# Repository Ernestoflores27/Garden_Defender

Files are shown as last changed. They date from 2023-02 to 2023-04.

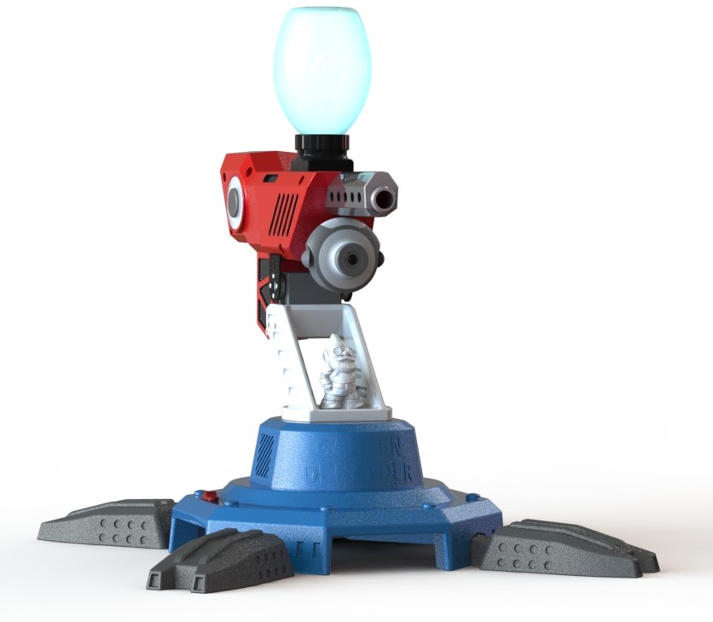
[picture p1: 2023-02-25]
Mechanical Design/Renders/V2/2.JPG

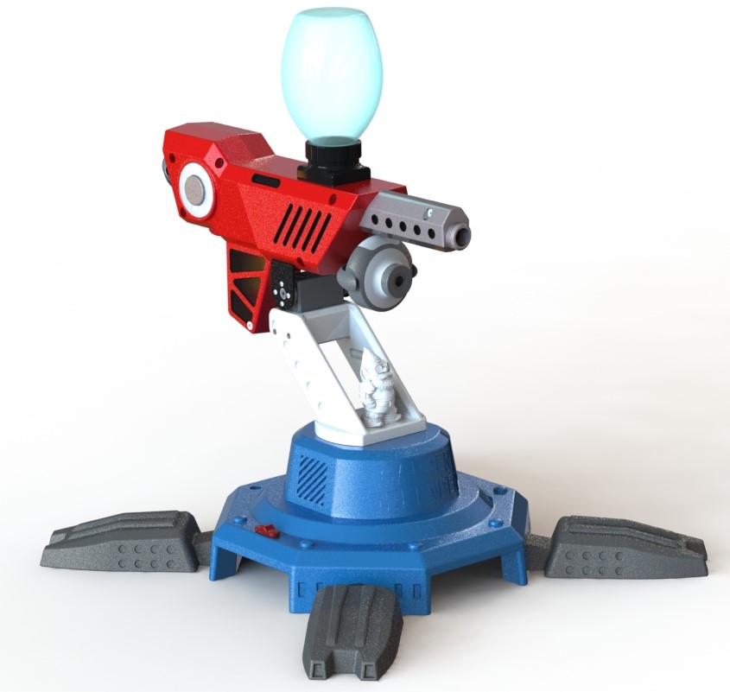
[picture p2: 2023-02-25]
Mechanical Design/Renders/V2/4.JPG

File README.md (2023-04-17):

# Garden_Defender   

Garden Defender Logo

# Description
WhatsApp Image 2023-04-06 at 18 43 52

Protect your garden from unwanted animals with the garden defender. The garden defender is a robotic water pellet gun that deters unwanted animals by shooting at them with a water pellet. The robotic gun will continuously scan your garden with a webcam. With the combination of computer vision and a deep learning algorithm “YOLO”, the garden defender can detect and distinguish between a “friendly” and “unwanted guest” before shooting a water pellet. 

# Details

In most cases, a fence or a garden wall is not enough to prevent unwanted animals visiting your garden. This is particular true for gardeners who like to grow vegetables. Animals such rats and birds might see your vegetables as free food. Or your neighbourhood cat might have taken a liking to your lawn as its personal toilet. 

One solution to deter these “unwanted guest” is by shooting at them with a water gel pellet. The garden defender has a webcam that continuously scans your garden. When an “unwanted guest is detected”, the garden defender with aim and shoot. 

## Features

- Detect unwanted guests: OpenCV and a deep learning algorithm “YOLO” was used for object detection. 
    
- Aim and shoot: When an unwanted guest is detected will aim and shoot
    
- Garden surveillance - large field of view: Robot will continuously move web cam left and right to maximise the field of view when an unwanted guest not detected.
    
Please, watch our video:

Garden_Defender (https://www.youtube.com/watch?v=-97-if4tLNQ)

# Documentation
For code documentation go to: 
https://ernestoflores27.github.io/Garden_Defender/html/index.html

# Build
For full building instructions go to:
[Full build guide](https://maeldorne.notion.site/Garden-Defender-f2392ed58dae446e874e89c7e9c0607c)

# Installation
**Required packages:**

- Raspberry Pi OS (previously called Raspbian): [https://www.raspberrypi.com/software/](https://www.raspberrypi.com/software/)
- Cmake: [https://cmake.org/download/](https://cmake.org/download/)
- Pigpio: [https://kalitut.com/control-gpio-pigpiod-commands/](https://kalitut.com/control-gpio-pigpiod-commands/)
- PCA9685: [https://www.adafruit.com/product/815](https://www.adafruit.com/product/815)
- OpenCV for C++ with DNN support: [https://opencv.org/](https://opencv.org/)

**Installing Raspberry Pi OS:**

1. Download package.
2. Install Raspberry Pi OS on your PC.
3. Insert SD card into your PC.
4. Open Raspberry Pi Imager.
5. In Operating system select: Raspberry Pi OS (32-bit)
6. In Storage select your SD card.
7. Select setting and add your WIFI name (SSID) and password.
8. Finally, click on Write.

**Installing Cmake on RPI:**

1.-Open terminal.

2.-Installation:

```bash
cd
sudo apt-get install cmake
```

3.-Verification:

```bash
cmake --version
```

**Installing Pigpio on RPI:**

1.-Open terminal.

2.-Installation:

```bash
cd
sudo apt-get install pigpio
```

3.- Verification:

```bash
pigpio --version
```

**Installing PCA9685 on RPI:**

1.Follow the installation as shown here: [https://github.com/vanvught/rpidmx512/tree/master/lib-pca9685](https://github.com/vanvught/rpidmx512/tree/master/lib-pca9685)

**Installing OpenCV on RPI:**

1.-Open terminal

2.-Download:

```bash
wget https://github.com/sol-prog/raspberry-pi-opencv/releases/download/opencv4rpi2.1/opencv-4.1.0-armhf.tar.bz2
```

3.-Extract:

```bash
tar xvf opencv-4.1.0-armhf.tar.bz2
```

4.-Move folder:

```bash
sudo mv opencv-4.1.0 /opt
```

5.-Remove folder:

```bash
rm opencv-4.1.0-armhf.tar.bz2
```

6.-Install requisites:

```bash
sudo apt install libtiff-dev zlib1g-dev
sudo apt install libjpeg-dev libpng-dev
sudo apt install libavcodec-dev libavformat-dev libswscale-dev libv4l-dev
sudo apt-get install libxvidcore-dev libx264-dev
```

7.-Add OpenCV to the system library path:

```bash
cd ~
echo 'export LD_LIBRARY_PATH=/opt/opencv-4.1.0/lib:$LD_LIBRARY_PATH' >> .bashrc. .bashrc
```
8.-Clone config file:
```bash
cd ~
echo 'export LD_LIBRARY_PATH=/opt/opencv-4.1.0/lib:$LD_LIBRARY_PATH' >> .bashrc. .bashrc
```

Clone this repo using 
```bash
git clone https://github.com/Ernestoflores27/Garden_Defender.git
```
Build using cmake
```bash
cd Garden_Defender
make
```

# Run
```bash
sudo Garden_Defender/build/garden_defender
```
# Unit Test
install google test
```bash
git clone https://github.com/google/googletest.git
cd googletest
mkdir build
cd build
cmake ..
make
sudo make install
```

Run test file
```bash
sudo Garden_Defender/build/Maintest
sudo Garden_Defender/build/Turrettest
sudo Garden_Defender/build/Servostest
```

# Our team
Maël Dorne 2806329D,
Ernesto Flores 2659823F,
Ming Jiao Wang 2834505W

# Social Media
[](https://www.instagram.com/gardendefender_info/)
[](https://www.youtube.com/@gardendefender)
[](https://twitter.com/garden_defender)
[](https://www.tiktok.com/@gardendefenderinfo)
[](https://www.facebook.com/profile.php?id=100089644931372)

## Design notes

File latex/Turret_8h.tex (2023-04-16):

\hypertarget{Turret_8h}{}\doxysection{Objects/\+Turret.h File Reference}
\label{Turret_8h}\index{Objects/Turret.h@{Objects/Turret.h}}

Class definition for the \mbox{\hyperlink{classTurret}{Turret}} class. It controls the turrent position by modifying the pitch and yaw.  

{\ttfamily \#include $<$pigpiod\+\_\+if2.\+h$>$}\newline
{\ttfamily \#include \char`\"{}Servos.\+cpp\char`\"{}}\newline
{\ttfamily \#include $<$time.\+h$>$}\newline
{\ttfamily \#include $<$thread$>$}\newline
Include dependency graph for Turret.\+h\+:
% FIG 0
\doxysubsection*{Classes}
\begin{DoxyCompactItemize}
\item 
class \mbox{\hyperlink{classTurret}{Turret}}
\begin{DoxyCompactList}\small\item\em \mbox{\hyperlink{classTurret}{Turret}} class definition. \end{DoxyCompactList}\end{DoxyCompactItemize}
\doxysubsection*{Macros}
\begin{DoxyCompactItemize}
\item 
\mbox{\Hypertarget{Turret_8h_a808773d72a1789efcf5b00860586c1fa}\label{Turret_8h_a808773d72a1789efcf5b00860586c1fa}} 
\#define {\bfseries SMOOTHING}~0.\+9
\item 
\mbox{\Hypertarget{Turret_8h_ab05a798afd72aac947f417e1dab73c87}\label{Turret_8h_ab05a798afd72aac947f417e1dab73c87}} 
\#define {\bfseries MARGIN}~0.\+2
\item 
\mbox{\Hypertarget{Turret_8h_aac3553b3932cbfeeac4526ce7ca0336b}\label{Turret_8h_aac3553b3932cbfeeac4526ce7ca0336b}} 
\#define {\bfseries SPEED}~1
\end{DoxyCompactItemize}

\doxysubsection{Detailed Description}
Class definition for the \mbox{\hyperlink{classTurret}{Turret}} class. It controls the turrent position by modifying the pitch and yaw.

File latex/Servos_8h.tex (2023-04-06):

\hypertarget{Servos_8h}{}\doxysection{Objects/\+Servos.h File Reference}
\label{Servos_8h}\index{Objects/Servos.h@{Objects/Servos.h}}

A class to control servos using PCA9685. This class allows to control servos using PCA9685 PWM driver. It provides a function to initialize the servos and another function to move each servo to a given angle.  

{\ttfamily \#include $<$Pi\+PCA9685/\+PCA9685.\+h$>$}\newline
{\ttfamily \#include $<$unistd.\+h$>$}\newline
Include dependency graph for Servos.\+h\+:
% FIG 0
\doxysubsection*{Classes}
\begin{DoxyCompactItemize}
\item 
class \mbox{\hyperlink{classServos}{Servos}}
\begin{DoxyCompactList}\small\item\em A class to control servos using PCA9685 PWM driver. \end{DoxyCompactList}\end{DoxyCompactItemize}

\doxysubsection{Detailed Description}
A class to control servos using PCA9685. This class allows to control servos using PCA9685 PWM driver. It provides a function to initialize the servos and another function to move each servo to a given angle.

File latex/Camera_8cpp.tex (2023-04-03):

\hypertarget{Camera_8cpp}{}\doxysection{Objects/\+Camera.cpp File Reference}
\label{Camera_8cpp}\index{Objects/Camera.cpp@{Objects/Camera.cpp}}

This file defines a \mbox{\hyperlink{classCamera}{Camera}} class that allows setting up a camera and obtaining a video stream.  

{\ttfamily \#include $<$opencv4/opencv2/opencv.\+hpp$>$}\newline
Include dependency graph for Camera.\+cpp\+:

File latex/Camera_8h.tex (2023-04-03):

\hypertarget{Camera_8h}{}\doxysection{Objects/\+Camera.h File Reference}
\label{Camera_8h}\index{Objects/Camera.h@{Objects/Camera.h}}

This file defines a \mbox{\hyperlink{classCamera}{Camera}} class that allows setting up a camera and obtaining a video stream.  

{\ttfamily \#include $<$opencv4/opencv2/opencv.\+hpp$>$}\newline
Include dependency graph for Camera.\+h\+:

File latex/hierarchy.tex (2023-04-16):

\doxysection{Class Hierarchy}
This inheritance list is sorted roughly, but not completely, alphabetically\+:\begin{DoxyCompactList}
\item \contentsline{section}{Detector\+::Callback\+\_\+\+Detector}{\pageref{structDetector_1_1Callback__Detector}}{}
\begin{DoxyCompactList}
\item \contentsline{section}{Callback\+\_\+\+Detector}{\pageref{classCallback__Detector}}{}
\end{DoxyCompactList}
\item \contentsline{section}{GUI\+::Callback\+\_\+\+GUI}{\pageref{structGUI_1_1Callback__GUI}}{}
\begin{DoxyCompactList}
\item \contentsline{section}{Callback\+\_\+\+GUI}{\pageref{classCallback__GUI}}{}
\end{DoxyCompactList}
\item \contentsline{section}{Camera}{\pageref{classCamera}}{}
\item \contentsline{section}{Detector}{\pageref{classDetector}}{}
\item \contentsline{section}{GUI}{\pageref{classGUI}}{}
\item \contentsline{section}{Object}{\pageref{classObject}}{}
\item \contentsline{section}{Servos}{\pageref{classServos}}{}
\item \contentsline{section}{Turret}{\pageref{classTurret}}{}
\end{DoxyCompactList}

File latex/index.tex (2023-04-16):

\label{index_md_README}%
\Hypertarget{index_md_README}%
 \hypertarget{index_autotoc_md1}{}\doxysection{Description}\label{index_autotoc_md1}

Protect your garden from unwanted animals with the garden defender. The garden defender is a robotic water pellet gun that deters unwanted animals by shooting at them with a water pellet. The robotic gun will continuously scan your garden with a webcam. With the combination of computer vision and a deep learning algorithm “\+YOLO”, the garden defender can detect and distinguish between a “friendly” and “unwanted guest” before shooting a water pellet.\hypertarget{index_autotoc_md2}{}\doxysection{Details}\label{index_autotoc_md2}
In most cases, a fence or a garden wall is not enough to prevent unwanted animals visiting your garden. This is particular true for gardeners who like to grow vegetables. Animals such rats and birds might see your vegetables as free food. Or your neighbourhood cat might have taken a liking to your lawn as its personal toilet.

One solution to deter these “unwanted guest” is by shooting at them with a water gel pellet. The garden defender has a webcam that continuously scans your garden. When an “unwanted guest is detected”, the garden defender with aim and shoot.\hypertarget{index_autotoc_md3}{}\doxysubsection{Features}\label{index_autotoc_md3}

\begin{DoxyItemize}
\item Detect unwanted guests\+: Open\+CV and a deep learning algorithm “\+YOLO” was used for object detection.
\item Aim and shoot\+: When an unwanted guest is detected will aim and shoot
\item Garden surveillance -\/ large field of view\+: Robot will continuously move web cam left and right to maximise the field of view when an unwanted guest not detected.
\end{DoxyItemize}

Please, watch our video\+:

\href{https://www.youtube.com/watch?v=-97-if4tLNQ}{\texttt{ }}\hypertarget{index_autotoc_md4}{}\doxysection{Documentation}\label{index_autotoc_md4}
For code documentation go to\+: \href{https://ernestoflores27.github.io/Garden_Defender/html/index.html}{\texttt{ https\+://ernestoflores27.\+github.\+io/\+Garden\+\_\+\+Defender/html/index.\+html}}\hypertarget{index_autotoc_md5}{}\doxysection{Build}\label{index_autotoc_md5}
For full building instructions go to\+: \href{https://maeldorne.notion.site/Garden-Defender-f2392ed58dae446e874e89c7e9c0607c}{\texttt{ Full build guide}}\hypertarget{index_autotoc_md6}{}\doxysection{Installation}\label{index_autotoc_md6}
{\bfseries{Required packages\+:}}

\begin{DoxyItemize}
\item Raspberry Pi OS (previously called Raspbian)\+: \href{https://www.raspberrypi.com/software/}{\texttt{ https\+://www.\+raspberrypi.\+com/software/}}
\item Cmake\+: \href{https://cmake.org/download/}{\texttt{ https\+://cmake.\+org/download/}}
\item Pigpio\+: \href{https://kalitut.com/control-gpio-pigpiod-commands/}{\texttt{ https\+://kalitut.\+com/control-\/gpio-\/pigpiod-\/commands/}}
\item PCA9685\+: \href{https://www.adafruit.com/product/815}{\texttt{ https\+://www.\+adafruit.\+com/product/815}}
\item Open\+CV for C++ with DNN support\+: \href{https://opencv.org/}{\texttt{ https\+://opencv.\+org/}}
\end{DoxyItemize}

{\bfseries{Installing Raspberry Pi OS\+:}}

\begin{DoxyEnumerate}
\item Download package.
\item Install Raspberry Pi OS on your PC.
\item Insert SD card into your PC.
\item Open Raspberry Pi Imager.
\item In Operating system select\+: Raspberry Pi OS (32-\/bit)
\item In Storage select your SD card.
\item Select setting and add your WIFI name (SSID) and password.
\item Finally, click on Write.
\end{DoxyEnumerate}

{\bfseries{Installing Cmake on RPI\+:}}

1.-\/Open terminal.

2.-\/Installation\+:

\begin{DoxyCode}{0}
\DoxyCodeLine{cd}
\DoxyCodeLine{sudo apt-\/get install cmake}

\end{DoxyCode}

3.-\/Verification\+:

\begin{DoxyCode}{0}
\DoxyCodeLine{cmake -\/-\/version}

\end{DoxyCode}

{\bfseries{Installing Pigpio on RPI\+:}}

1.-\/Open terminal.

2.-\/Installation\+:

\begin{DoxyCode}{0}
\DoxyCodeLine{cd}
\DoxyCodeLine{sudo apt-\/get install pigpio}

\end{DoxyCode}

3.-\/ Verification\+:

\begin{DoxyCode}{0}
\DoxyCodeLine{pigpio -\/-\/version}

\end{DoxyCode}

{\bfseries{Installing PCA9685 on RPI\+:}}

1.\+Follow the installation as shown here\+: \href{https://github.com/vanvught/rpidmx512/tree/master/lib-pca9685}{\texttt{ https\+://github.\+com/vanvught/rpidmx512/tree/master/lib-\/pca9685}}

{\bfseries{Installing Open\+CV on RPI\+:}}

1.-\/Open terminal

2.-\/Download\+:

\begin{DoxyCode}{0}
\DoxyCodeLine{wget https://github.com/sol-\/prog/raspberry-\/pi-\/opencv/releases/download/opencv4rpi2.1/opencv-\/4.1.0-\/armhf.tar.bz2}

\end{DoxyCode}

3.-\/Extract\+:

\begin{DoxyCode}{0}
\DoxyCodeLine{tar xvf opencv-\/4.1.0-\/armhf.tar.bz2}

\end{DoxyCode}

4.-\/Move folder\+:

\begin{DoxyCode}{0}
\DoxyCodeLine{sudo mv opencv-\/4.1.0 /opt}

\end{DoxyCode}

5.-\/Remove folder\+:

\begin{DoxyCode}{0}
\DoxyCodeLine{rm opencv-\/4.1.0-\/armhf.tar.bz2}

\end{DoxyCode}

6.-\/Install requisites\+:

\begin{DoxyCode}{0}
\DoxyCodeLine{sudo apt install libtiff-\/dev zlib1g-\/dev}
\DoxyCodeLine{sudo apt install libjpeg-\/dev libpng-\/dev}
\DoxyCodeLine{sudo apt install libavcodec-\/dev libavformat-\/dev libswscale-\/dev libv4l-\/dev}
\DoxyCodeLine{sudo apt-\/get install libxvidcore-\/dev libx264-\/dev}

\end{DoxyCode}

7.-\/Add Open\+CV to the system library path\+:

\begin{DoxyCode}{0}
\DoxyCodeLine{cd \string~}
\DoxyCodeLine{echo 'export LD\_LIBRARY\_PATH=/opt/opencv-\/4.1.0/lib:\$LD\_LIBRARY\_PATH' >> .bashrc. .bashrc}

\end{DoxyCode}
 8.-\/Clone config file\+: 
\begin{DoxyCode}{0}
\DoxyCodeLine{cd \string~}
\DoxyCodeLine{echo 'export LD\_LIBRARY\_PATH=/opt/opencv-\/4.1.0/lib:\$LD\_LIBRARY\_PATH' >> .bashrc. .bashrc}

\end{DoxyCode}

Clone this repo using 
\begin{DoxyCode}{0}
\DoxyCodeLine{git clone https://github.com/Ernestoflores27/Garden\_Defender.git}

\end{DoxyCode}
 Build using cmake 
\begin{DoxyCode}{0}
\DoxyCodeLine{cd Garden\_Defender}
\DoxyCodeLine{make}

\end{DoxyCode}
\hypertarget{index_autotoc_md7}{}\doxysection{Run}\label{index_autotoc_md7}

\begin{DoxyCode}{0}
\DoxyCodeLine{sudo Garden\_Defender/build/garden\_defender}

\end{DoxyCode}
\hypertarget{index_autotoc_md8}{}\doxysection{Social Media}\label{index_autotoc_md8}
\href{https://www.instagram.com/gardendefender_info/}{\texttt{ }} \href{https://www.youtube.com/@gardendefender}{\texttt{ }} \href{https://twitter.com/garden_defender}{\texttt{ }} \href{https://www.tiktok.com/@gardendefenderinfo}{\texttt{ }} \href{https://www.facebook.com/profile.php?id=100089644931372}{\texttt{ }}

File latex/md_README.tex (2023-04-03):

\hypertarget{md_README_autotoc_md1}{}\doxysection{Description}\label{md_README_autotoc_md1}
Protect your garden from unwanted animals with the garden defender. The garden defender is a robotic water pellet gun that deters unwanted animals by shooting at them with a water pellet. The robotic gun will continuously scan your garden with a webcam. With the combination of computer vision and a deep learning algorithm “\+YOLO”, the garden defender can detect and distinguish between a “friendly” and “unwanted guest” before shooting a water pellet.\hypertarget{md_README_autotoc_md2}{}\doxysection{Details}\label{md_README_autotoc_md2}
In most cases, a fence or a garden wall is not enough to prevent unwanted animals visiting your garden. This is particular true for gardeners who like to grow vegetables. Animals such rats and birds might see your vegetables as free food. Or your neighbourhood cat might have taken a liking to your lawn as its personal toilet.

One solution to deter these “unwanted guest” is by shooting at them with a water gel pellet. The garden defender has a webcam that continuously scans your garden. When an “unwanted guest is detected”, the garden defender with aim and shoot.\hypertarget{md_README_autotoc_md3}{}\doxysubsection{Features}\label{md_README_autotoc_md3}

\begin{DoxyItemize}
\item Detect unwanted guests

Open\+CV and a deep learning algorithm “\+YOLO” was used for object detection.
\item Aim and shoot

When an unwanted guest is detected will aim and shoot
\item Garden surveillance -\/ large field of view

Robot will continuously move web cam left and right to maximise the field of view when an unwanted guest not detected.
\end{DoxyItemize}\hypertarget{md_README_autotoc_md4}{}\doxysection{Build}\label{md_README_autotoc_md4}
For full building instructions go to\+: \href{https://maeldorne.notion.site/Garden-Defender-f2392ed58dae446e874e89c7e9c0607c}{\texttt{ Full build guide}}

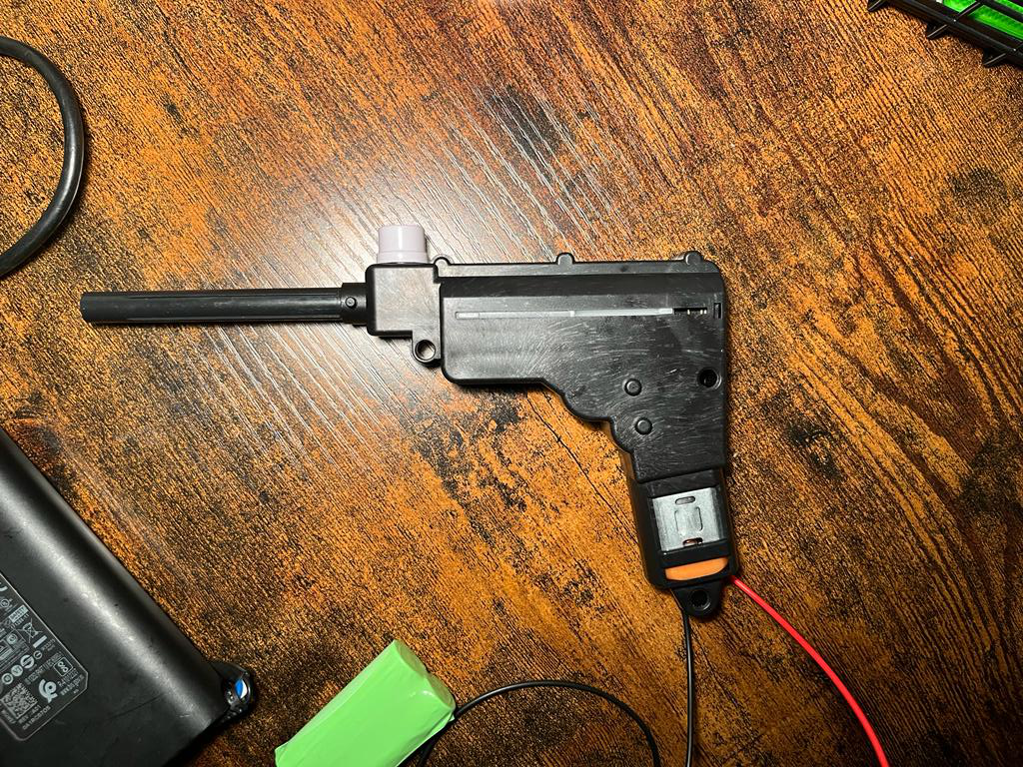
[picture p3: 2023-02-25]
Mechanical Design/SOLIDWORKS/Gel Blaster.jpg

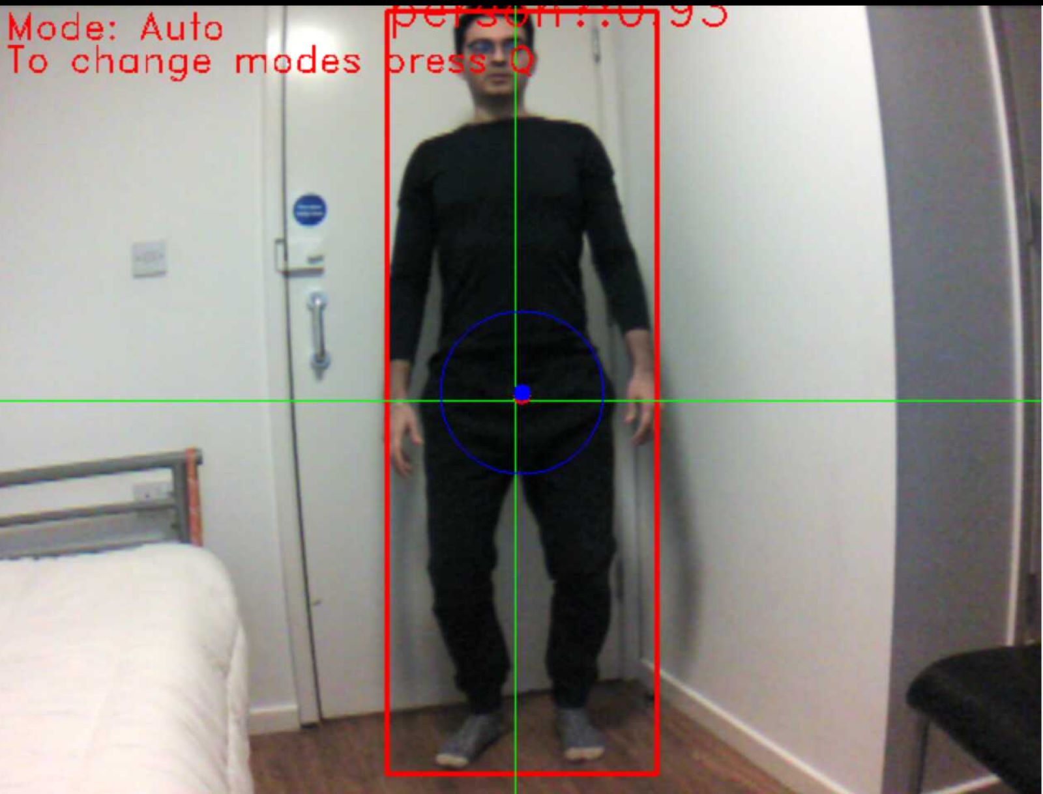
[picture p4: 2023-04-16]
assets/AutoMode.jpg

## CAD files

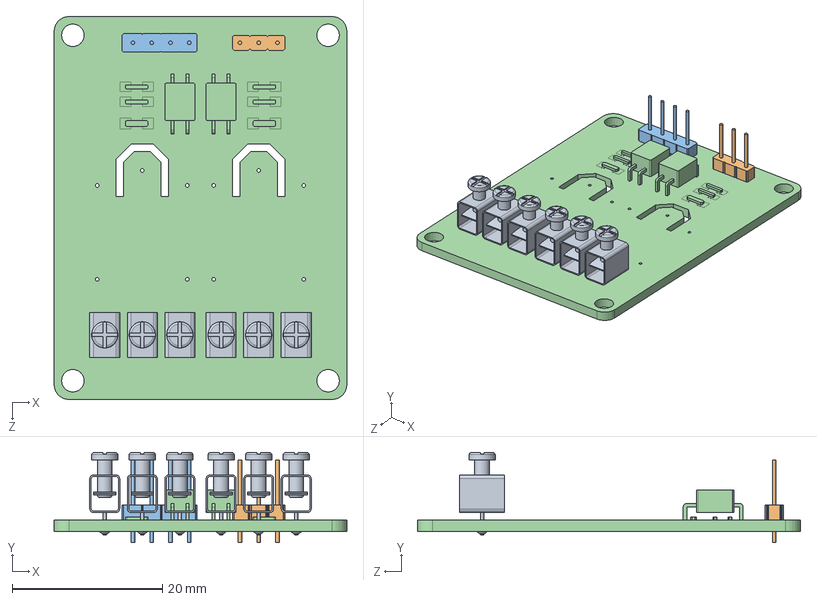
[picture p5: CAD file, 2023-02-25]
Mechanical Design/SOLIDWORKS/Relay Module/Relay - 2 Channel.SLDASM
39.0 x 12.0 x 51.0 mm
2PH63091A Board
4 Headers
Headers
Metal Clamp Part x 6

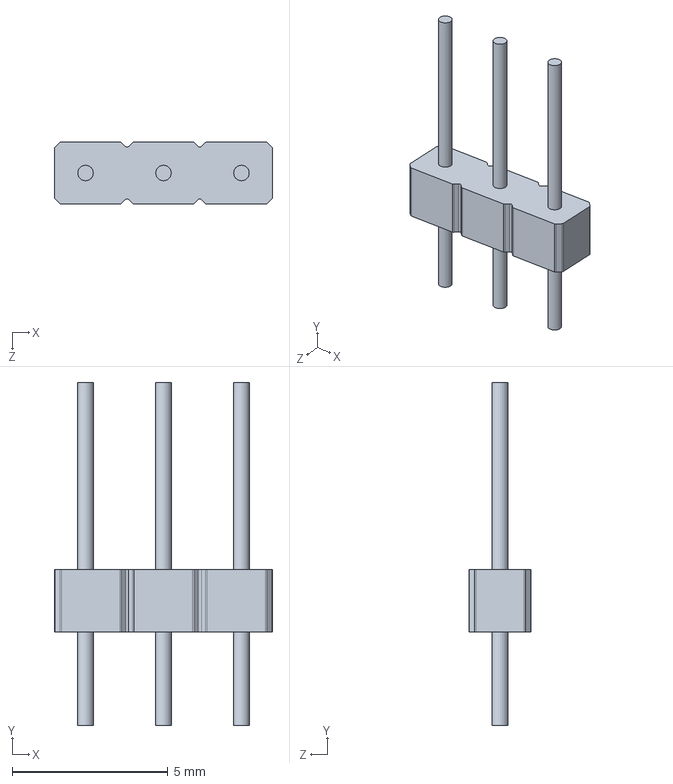
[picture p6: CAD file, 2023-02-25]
Mechanical Design/SOLIDWORKS/Relay Module/Headers.SLDPRT
7.00 x 11.0 x 2.00 mm

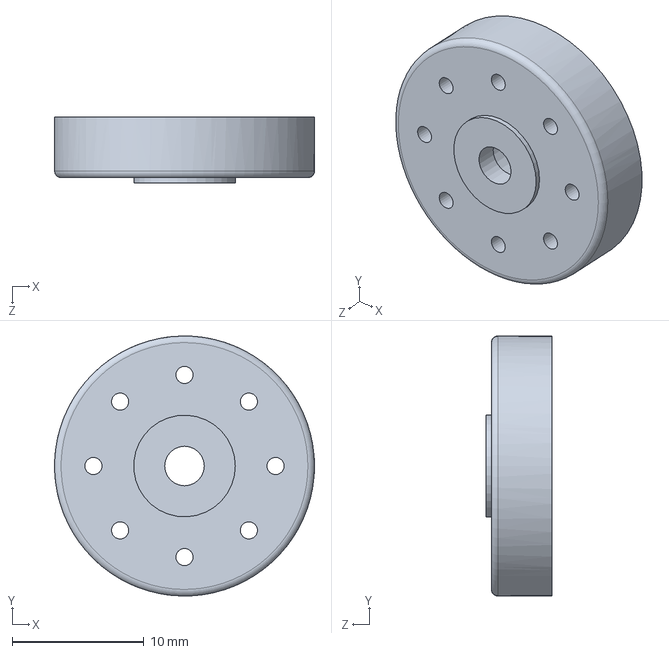
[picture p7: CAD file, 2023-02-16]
Mechanical Design/SOLIDWORKS/Servo LDX-218/LDX-218_Mounting_Disk.SLDPRT
19.7 x 19.7 x 5.00 mm

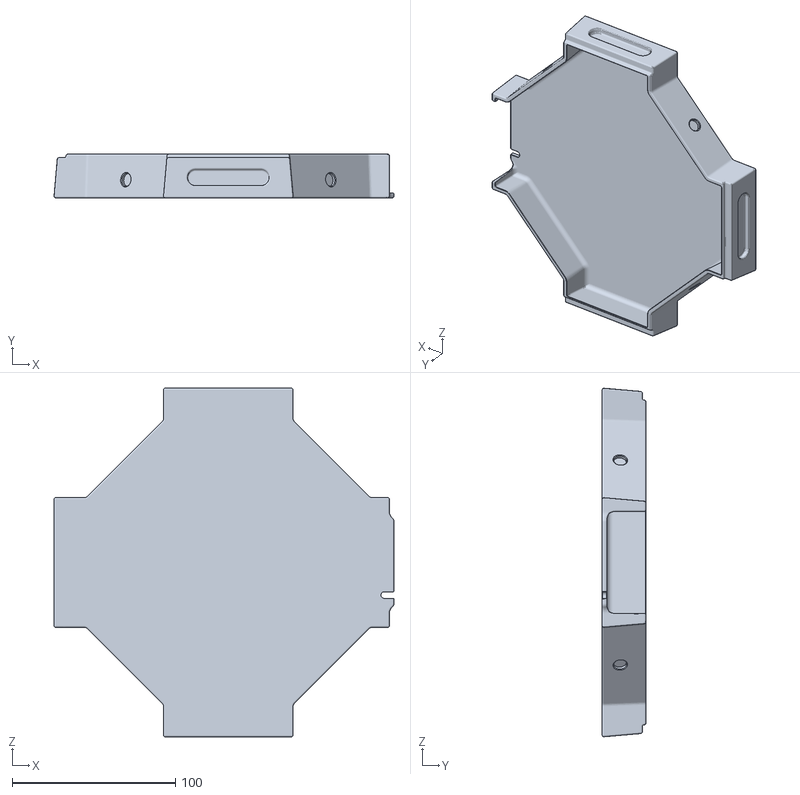
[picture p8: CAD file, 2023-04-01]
Mechanical Design/STL Files/Electronics_Cover_x1.STL
208.5 x 26.8 x 213.8

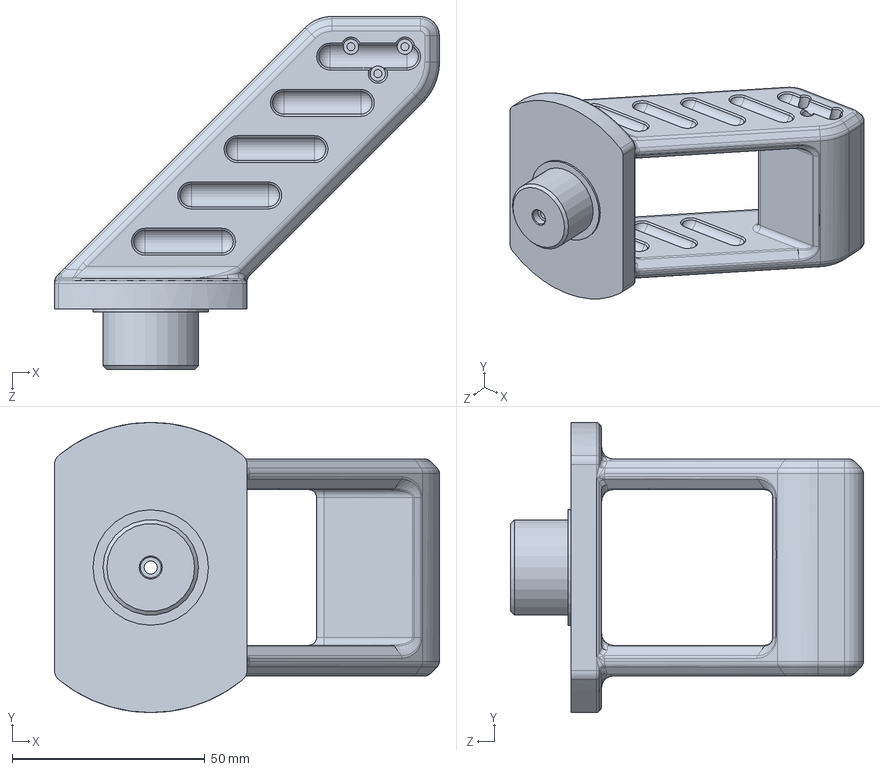
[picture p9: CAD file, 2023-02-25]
Mechanical Design/SOLIDWORKS/Link.SLDPRT
100.0 x 75.4 x 91.7 mm

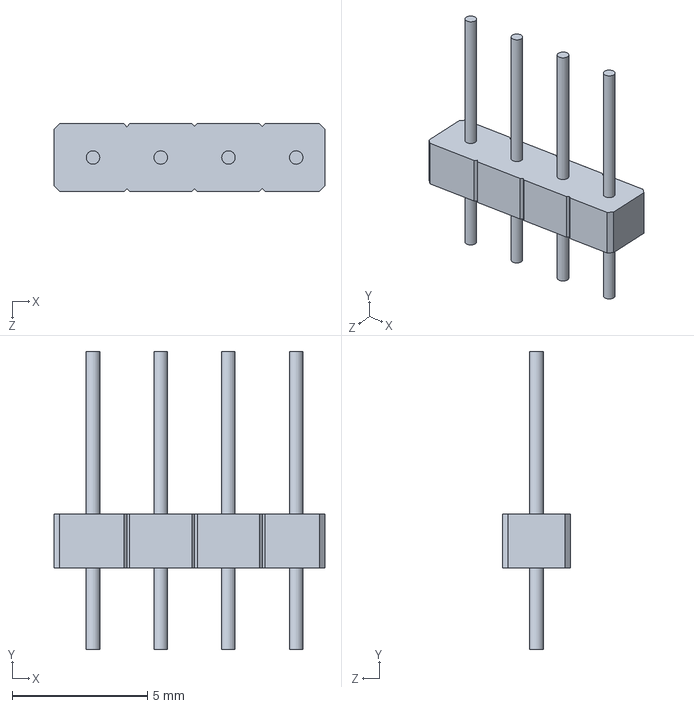
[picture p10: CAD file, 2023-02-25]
Mechanical Design/SOLIDWORKS/Relay Module/4 Headers.SLDPRT
10.0 x 11.0 x 2.50 mm

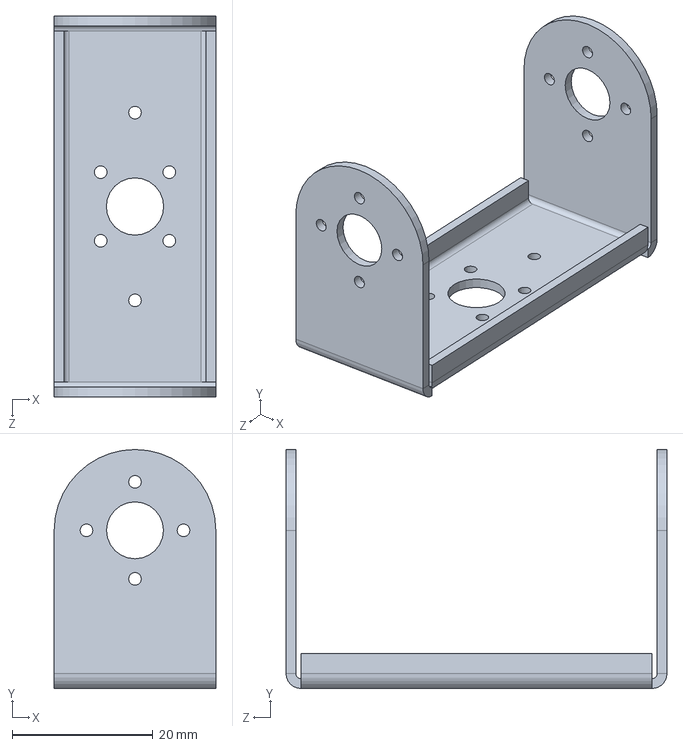
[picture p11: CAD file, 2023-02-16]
Mechanical Design/SOLIDWORKS/Servo LDX-218/LDX-218_Large_Bracket.SLDPRT
23.0 x 34.0 x 54.2 mm

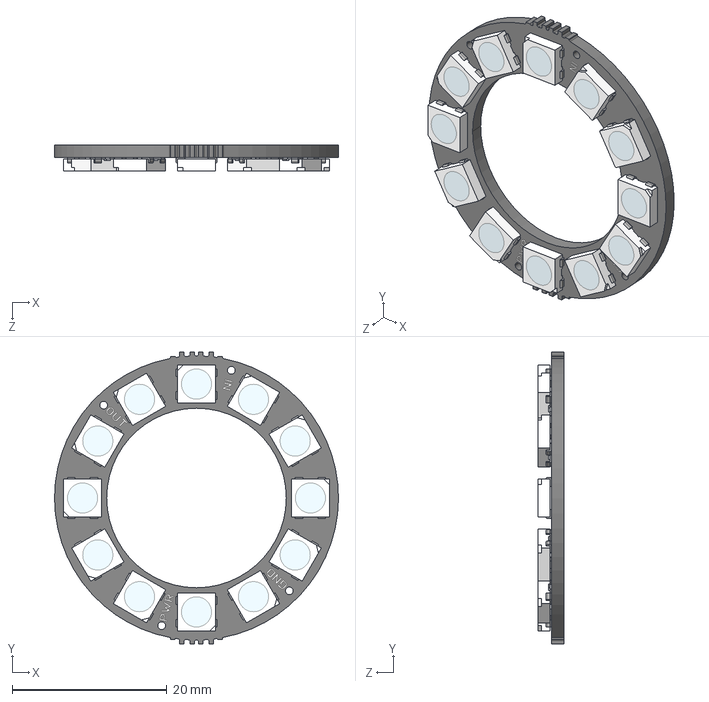
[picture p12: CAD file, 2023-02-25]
Mechanical Design/STEP Files/Neopixel Ring 12x_Predeterminado.STEP
36.7 x 37.7 x 3.31 mm

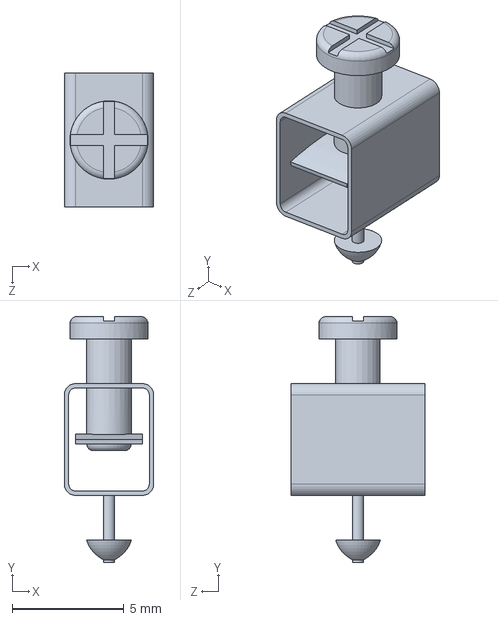
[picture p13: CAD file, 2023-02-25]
Mechanical Design/SOLIDWORKS/Relay Module/Metal Clamp Part.SLDPRT
4.00 x 11.0 x 6.00 mm

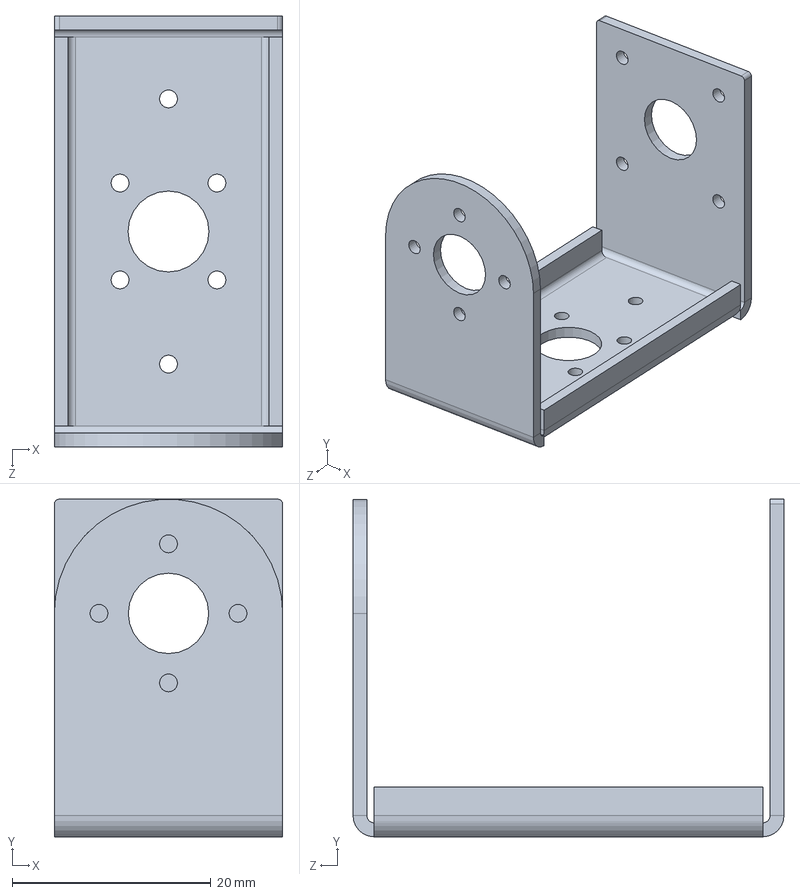
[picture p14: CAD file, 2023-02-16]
Mechanical Design/SOLIDWORKS/Servo LDX-218/LDX-218_Small_Bracket.SLDPRT
23.0 x 34.0 x 43.4 mm

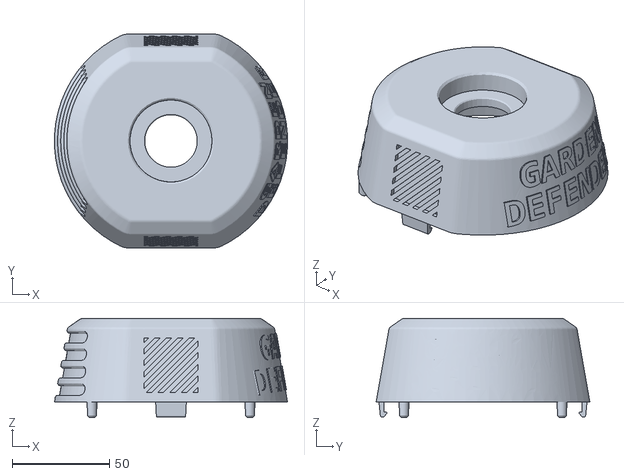
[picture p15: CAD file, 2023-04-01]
Mechanical Design/STL Files/Cover_x1.STL
119.9 x 110.0 x 51.1

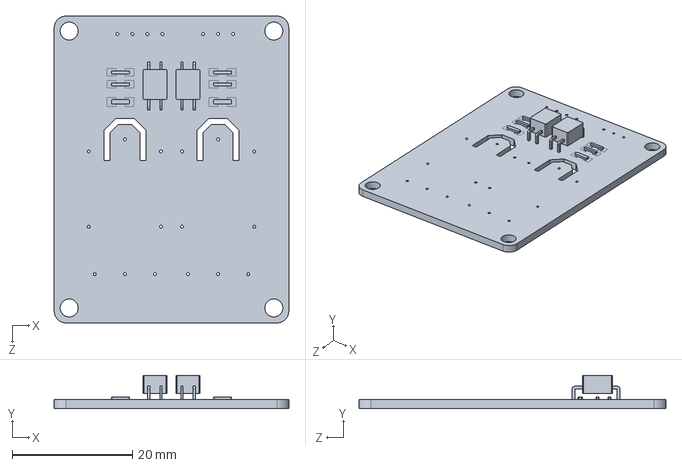
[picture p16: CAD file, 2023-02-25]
Mechanical Design/SOLIDWORKS/Relay Module/2PH63091A Board.SLDPRT
39.0 x 5.50 x 51.0 mm

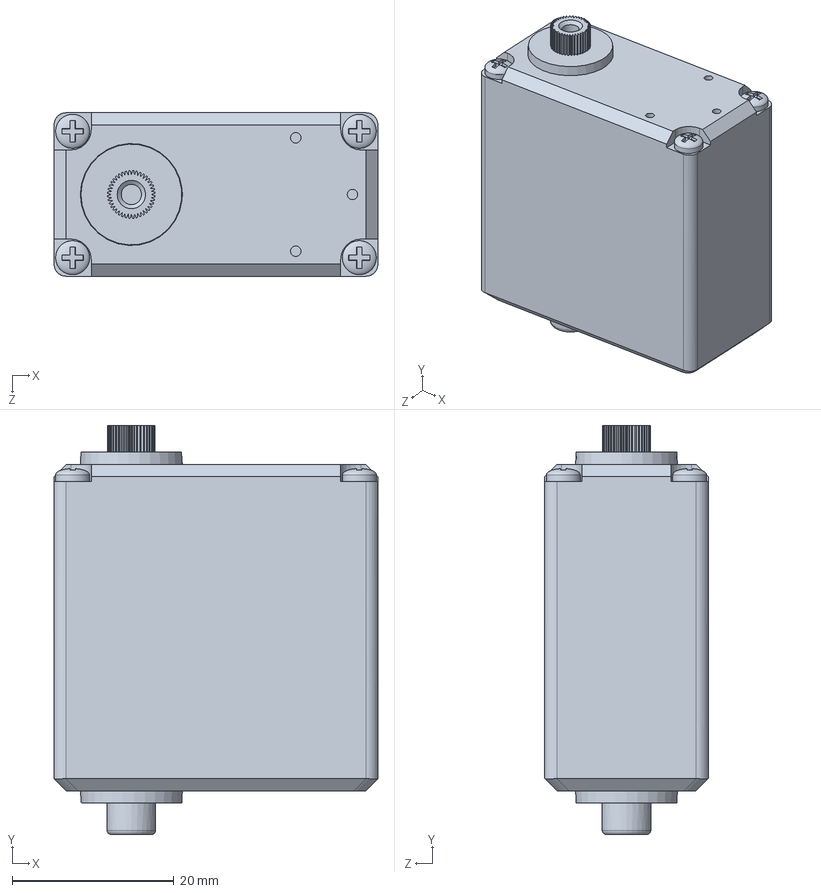
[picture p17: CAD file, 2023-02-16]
Mechanical Design/SOLIDWORKS/Servo LDX-218/LDX-218_Servo.SLDPRT
40.0 x 50.5 x 20.2 mm

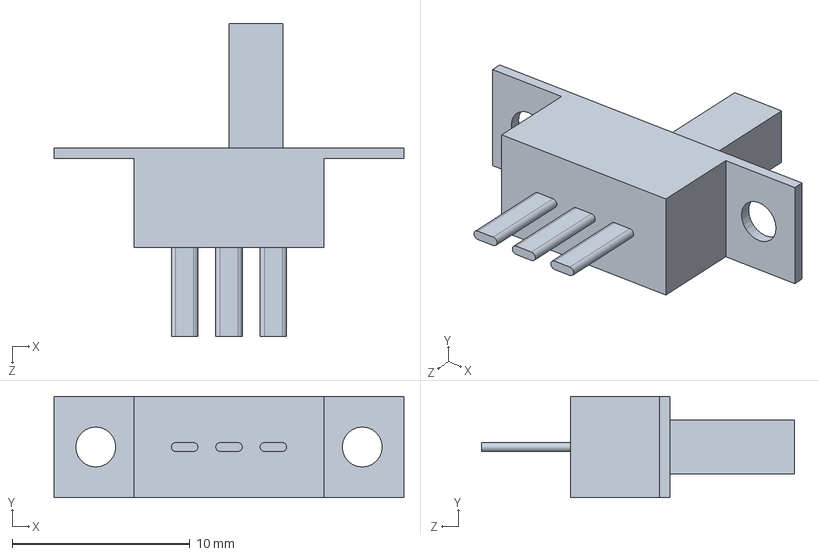
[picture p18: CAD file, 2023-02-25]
Mechanical Design/SOLIDWORKS/Switch.SLDPRT
19.7 x 5.70 x 17.6 mm

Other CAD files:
Mechanical Design/STEP Files/Blaster_Predeterminado_asm.STEP
Mechanical Design/STL Files/Link_x1.STL
Mechanical Design/STEP Files/Gnome_Predeterminado.STEP
Mechanical Design/STL Files/Foot_x4.STL
Mechanical Design/SOLIDWORKS/Ball Bearing 5972K246.SLDPRT
Mechanical Design/SOLIDWORKS/Blaster.SLDPRT
Mechanical Design/SOLIDWORKS/Button.SLDPRT
Mechanical Design/SOLIDWORKS/Camera.SLDPRT
Mechanical Design/SOLIDWORKS/Cover.SLDPRT
Mechanical Design/SOLIDWORKS/Flat Head Screw M3 x 10mm 91294A130.SLDPRT
Mechanical Design/SOLIDWORKS/Flat Head Screw M3 x 20mm 91294A136.SLDPRT
Mechanical Design/SOLIDWORKS/Flat Head Screw M4 x 12mm 91294A192.SLDPRT
Mechanical Design/SOLIDWORKS/Flat Head Screw M5 x 16mm 91294A212.SLDPRT
Mechanical Design/SOLIDWORKS/Foot.SLDPRT
Mechanical Design/SOLIDWORKS/Heat Insert for Plastic_94180A331.SLDPRT
Mechanical Design/SOLIDWORKS/Heat Insert for Plastic_M4_94459A150.SLDPRT
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

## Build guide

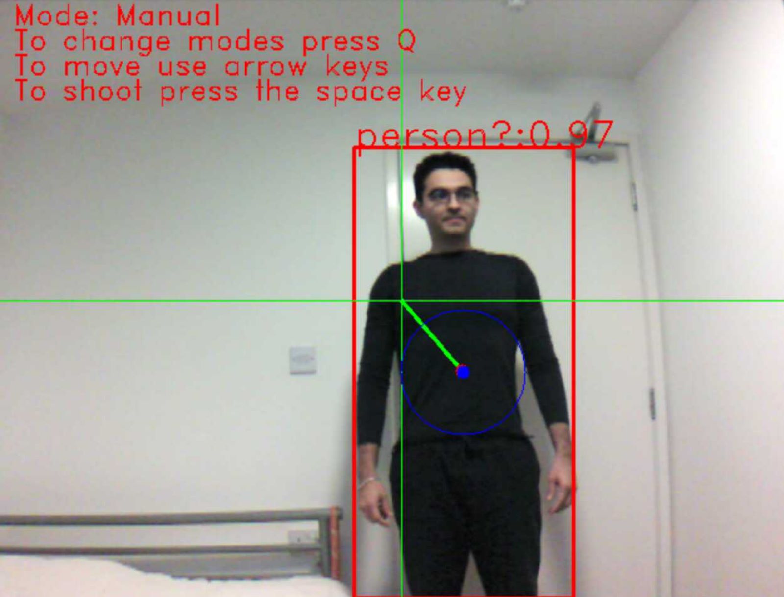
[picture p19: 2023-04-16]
assets/ManualMode.jpg

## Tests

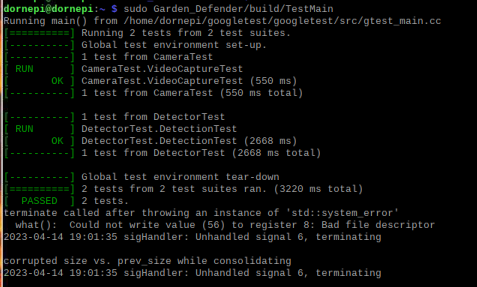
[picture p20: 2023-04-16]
assets/TestMain.png

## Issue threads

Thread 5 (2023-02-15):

Adjust bearing gaps.

Ernestoflores27, 2023-02-15:
After 3d printing Cover.stl and press fit the bearing, I need to adjust the tolerance in the design.

Closed 2023-02-15.

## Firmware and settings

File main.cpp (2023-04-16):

#include "Objects/Camera.cpp"
#include "Objects/Detector.cpp"
#include "Objects/Turret.cpp"
#include "Objects/GUI.cpp"
#include <opencv4/opencv2/opencv.hpp>
#include <unistd.h>
#include <iostream>

class Callback_Detector : public Detector::Callback_Detector
{
public:
	Turret *turret;
	Callback_Detector(Turret *turret_)
	{
		turret = turret_;
	}
	void callback_func(std::vector<Object> &objs_vector)
	{
		turret->objs_vector = objs_vector;
	}
};

class Callback_GUI : public GUI::Callback_GUI
{
public:
	Turret *turret;
	Callback_GUI(Turret *turret_)
	{
		turret = turret_;
	}
	void callback_func(int k)
	{
		if (k == 113)
			turret->manual = !turret->manual;
		else if (k == 82)
			turret->moveYaw(-5);
		else if (k == 84)
			turret->moveYaw(5);
		else if (k == 81)
			turret->movePitch(5);
		else if (k == 83)
			turret->movePitch(-5);
		else if (k == 32)
			turret->shoot();
	}
};

int main()
{
	// Init camera
	cv::Mat video_stream;
	Camera cam1(640, 480);
	cv::VideoCapture real_time = cam1.getVideoCapture();

	// Init Turret
	Turret turret(23, 24, 25);
	turret.changePosition(0, 0);
	turret.start();

	// Init Detector
	Callback_Detector ca_detector(&turret);
	Detector detector_model("Garden_Defender/Objects/yoloFastestV2.onnx", 0.3, 0.4, 0.4, real_time);
	detector_model.registerCallback(&ca_detector);
	detector_model.start();

	// Start GUI
	Callback_GUI ca_gui(&turret);
	GUI gui(&detector_model, &turret);
	gui.registerCallback(&ca_gui);
	gui.start();

	// Stop everything
	detector_model.stop();
	turret.stop();
}

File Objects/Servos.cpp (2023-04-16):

#include "Servos.h"
/**
/**
/**
 * @brief Default constructor for Servo object.
 * 
 */
Servos::Servos()
{
}
    /**
 * @brief Initializes the servos.
 * 
 * @param minPWM_ The minimum PWM value for the servos.
 * @param maxPWM_ The maximum PWM value for the servos.
 * @param minAngle_ The minimum angle value for the servos.
 * @param maxAngle_ The maximum angle value for the servos.
 */
void Servos::servoInit(float minPWM_, float maxPWM_, float minAngle_, float maxAngle_)
{
    minPWM = minPWM_;
    maxPWM = maxPWM_;
    minAngle = minAngle_;
    maxAngle = maxAngle_;
    pca.set_pwm_freq(50.0);
}
    /**
 * @brief Moves a servo to a given angle.
 * 
 * @param idx The index of the servo to move.
 * @param angle The angle to move the servo to.
 */
void Servos::servoMove(int idx, float angle)
{
    float pwm = mapAngleToPWM(angle);

    pca.set_pwm(idx, 0, pwm);
}
/**
 * @brief Maps an angle to PWM value.
 * 
 * @param angle The angle to map.
 * @return The corresponding PWM value.
 */
float Servos::mapAngleToPWM(float angle)
{
    return minPWM + (((maxPWM - minPWM) / (maxAngle - minAngle)) * (angle - minAngle));
}

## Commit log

2023-01-28 Servo testing in python
2023-01-31 Python test of relay
2023-01-31 Fixed Face detection for rpi
    [main.cpp]
2023-02-01 PCA9685 driver test
2023-02-03 Servo movement test
2023-02-04 Servo class
2023-02-04 Manual camera movement
2023-02-04 Removed unnecesary print
2023-02-15 Blaster designed
    [Blaster.SLDPRT]
2023-02-15 Blaster Case and Camera Design
    [Camera.SLDPRT, Phillips Thread-Forming Screw M2 x 10mm 99461A917.SLDPRT]
2023-02-15 New Camera added
    [Camera.SLDPRT]
2023-02-15 Blaster Assembly added
2023-02-16 Servo designed
    [LDX-218_Large_Bracket.SLDPRT, LDX-218_Mounting_Disk.SLDPRT, LDX-218_Servo.SLDPRT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]
2023-02-16 Blaster Case Draft
    [Ball Bearing 5972K246.SLDPRT, Button.SLDPRT, Camera.SLDPRT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]
2023-02-18 show video and control button on the web page
2023-02-25 Clean up Design
    [Ball Bearing 5972K246.SLDPRT, Blaster.SLDPRT, Button.SLDPRT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]
2023-02-25 Design SOLIDWORKS V2 finished
    [2PH63091A Board.SLDPRT, 4 Headers.SLDPRT, Clamp Body.SLDPRT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]
2023-02-25 STEP files added MD
    [2PH63091A Board_Varsayılan.STEP, 4 Headers_Varsayılan.STEP, Ball Bearing 5972K246_5972K246.STEP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]
2023-02-25 STL files for 3D printing
    [Blaster_Case_Barrel_Left.STL, Blaster_Case_Barrel_Right.STL, Blaster_Case_Left.STL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]
2023-03-01 Created thread to get and process an image
2023-03-07 Fixed old variable and class names
    [main.cpp]
2023-04-01 Last 3D models
    [Blaster_Case_Barrel_Left.STL, Blaster_Case_Barrel_Right.STL, Blaster_Case_Left.STL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]
2023-04-01 Printables added
2023-04-03 remove Camera.cpp
2023-04-15 reverted to no callback
    [main.cpp]
